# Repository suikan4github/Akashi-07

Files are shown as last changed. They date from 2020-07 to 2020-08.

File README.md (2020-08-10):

# Akashi-07
SDR front end prototype for NUCLEO G431RB and F722ZE

## Functionality
This board is designed for testing the SDR with Quadrature Sampling Detector. 
The connectors can be directly mounted on the Arduino mono Rev3.

The design can be retrieved from the [github](https://github.com/suikan4github/Akashi-07) repository.

The schematics [can be downloaded](docs/Akashi-07.pdf) as PDF format. 

| Function | NUCLEO-G431RB | NUCLEO-F722ZE |
|---|---|---|
| I2C1 SCL | PB8 | PB8 |
| I2C1 SDA | PB9 | PB9 |
| RESCUE | PC9 | PC9 |

The configuration of special ports are :

- PC9 : Open Drain output. To save the struggled I2C device.

## I2C address
The I2C device address of Si5351 PLL is configured as ***0x60*** ( 7bit address ).

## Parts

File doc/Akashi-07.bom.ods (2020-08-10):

Reference | Value | Footprint | Datasheet | DigiKey
C1 | 0.1u | Capacitors_THT:C_Disc_D4.7mm_W2.5mm_P5.00mm | ~
C10 | 0.1u | Capacitors_THT:C_Disc_D4.7mm_W2.5mm_P5.00mm | ~
C11 | 0.01u | Capacitors_THT:C_Disc_D4.7mm_W2.5mm_P5.00mm | ~
C12 | 0.01u | Capacitors_THT:C_Disc_D4.7mm_W2.5mm_P5.00mm | ~
C13 | 10u | Capacitors_THT:CP_Radial_D8.0mm_P2.50mm | ~
C14 | 47u | Capacitors_THT:CP_Radial_D8.0mm_P2.50mm | ~
C15 | 47u | Capacitors_THT:CP_Radial_D8.0mm_P2.50mm | ~
C16 | 47u | Capacitors_THT:CP_Radial_D8.0mm_P2.50mm | ~
C17 | 0.1u | Capacitors_THT:C_Disc_D4.7mm_W2.5mm_P5.00mm | ~
C18 | 0.1u | Capacitors_THT:C_Disc_D4.7mm_W2.5mm_P5.00mm | ~
C19 | 47u | Capacitors_THT:CP_Radial_D8.0mm_P2.50mm | ~
C2 | 0.1u | Capacitors_THT:C_Disc_D4.7mm_W2.5mm_P5.00mm | ~
C3 | 0.1u | Capacitors_THT:C_Disc_D4.7mm_W2.5mm_P5.00mm | ~
C4 | 0.1u | Capacitors_THT:C_Disc_D4.7mm_W2.5mm_P5.00mm | ~
C5 | 0.1u | Capacitors_THT:C_Disc_D4.7mm_W2.5mm_P5.00mm | ~
C6 | 0.1u | Capacitors_THT:C_Disc_D4.7mm_W2.5mm_P5.00mm | ~
C7 | 10u | Capacitors_THT:CP_Radial_D8.0mm_P2.50mm | ~
C8 | 0.1u | Capacitors_THT:C_Disc_D4.7mm_W2.5mm_P5.00mm | ~
C9 | 0.1u | Capacitors_THT:C_Disc_D4.7mm_W2.5mm_P5.00mm | ~
J1 | Conn_Coaxial | Connectors:SMA_THT_Jack_Straight | ~ | WM5543-ND
J2 | Screw_Terminal_01x02 | Connectors_Terminal_Blocks:TerminalBlock_bornier-2_P5.08mm | ~ | 281-2888-ND
J3 | SJ1-3533 | project_lib:Jack_3.5mm_CUI_SJ1-3533NG_Horizontal_CircularHoles | https://www.digikey.jp/product-detail/ja/cui-devices/SJ1-3533/CP1-3533-ND/738695 | CP1-3533N-ND
J4 | Conn_01x08 | Pin_Headers:Pin_Header_Straight_1x08_Pitch2.54mm | ~
J5 | Conn_01x06 | Pin_Headers:Pin_Header_Straight_1x06_Pitch2.54mm | ~
J6 | Conn_01x10 | Pin_Headers:Pin_Header_Straight_1x10_Pitch2.54mm | ~
J7 | Conn_01x08 | Pin_Headers:Pin_Header_Straight_1x08_Pitch2.54mm | ~
JP1 | Jumper_3_Open | Pin_Headers:Pin_Header_Straight_1x03_Pitch2.54mm | ~
JP2 | Jumper_3_Open | Pin_Headers:Pin_Header_Straight_1x03_Pitch2.54mm | ~
L1 | 10mH | Inductors_THT:L_Axial_L7.0mm_D3.3mm_P5.08mm_Vertical_Fastron_MICC | https://www.digikey.jp/product-detail/en/tdk-electronics-inc/B82144A2106J000/495-5615-1-ND/4245955 | AIAP-01-102K-TCT-ND
R1 | 2.2k | Resistors_THT:R_Axial_DIN0204_L3.6mm_D1.6mm_P2.54mm_Vertical | ~
R2 | 2.2k | Resistors_THT:R_Axial_DIN0204_L3.6mm_D1.6mm_P2.54mm_Vertical | ~
R3 | 3.3k | Resistors_THT:R_Axial_DIN0204_L3.6mm_D1.6mm_P2.54mm_Vertical | ~
R4 | 3.3k | Resistors_THT:R_Axial_DIN0204_L3.6mm_D1.6mm_P2.54mm_Vertical | ~
R5 | 100 | Resistors_THT:R_Axial_DIN0204_L3.6mm_D1.6mm_P2.54mm_Vertical | ~
R6 | 100 | Resistors_THT:R_Axial_DIN0204_L3.6mm_D1.6mm_P2.54mm_Vertical | ~
TP1 | TestPoint | Measurement_Points:Measurement_Point_Round-TH_Big | ~
TP2 | TestPoint | Measurement_Points:Measurement_Point_Round-TH_Big | ~
TP3 | TestPoint | Measurement_Points:Measurement_Point_Round-TH_Big | ~
TP4 | TestPoint | Measurement_Points:Measurement_Point_Round-TH_Big | ~
TP5 | TestPoint | Measurement_Points:Measurement_Point_Round-TH_Big | ~
TP6 | TestPoint | Measurement_Points:Measurement_Point_Round-TH_Big | ~
U1 | Si5351A-B-GT | Housings_SSOP:MSOP-10_3x3mm_Pitch0.5mm | https://www.silabs.com/documents/public/data-sheets/Si5351-B.pdf | 336-2399-5-ND
U2 | SN74LVC74APW | Housings_SSOP:TSSOP-14_4.4x5mm_Pitch0.65mm | https://www.tij.co.jp/product/jp/SN74LVC74A | 296-1241-1-ND
U3 | TS5A23157DGSR | project_lib:TS5A23157DGSR | https://www.tij.co.jp/product/jp/TS5A23157 | 296-17076-1-ND
U4 | AD8032ANZ | Housings_DIP:DIP-8_W7.62mm | https://www.analog.com/media/en/technical-documentation/data-sheets/AD8031_8032.pdf | AD8032ANZ-ND
U5 | TLV73333PDBVR | TO_SOT_Packages_SMD:SOT-23-5-handsoldering |  | 296-40673-1-ND
X1 | CSX-750FBC25000000T | Oscillators:Oscillator_SMD_SeikoEpson_SG8002CA-4pin_7.0x5.0mm_HandSoldering | https://www.digikey.jp/product-detail/ja/citizen-finedevice-co-ltd/CSX-750FBC25000000T/300-7246-1-ND/482134 | 300-7246-1-ND

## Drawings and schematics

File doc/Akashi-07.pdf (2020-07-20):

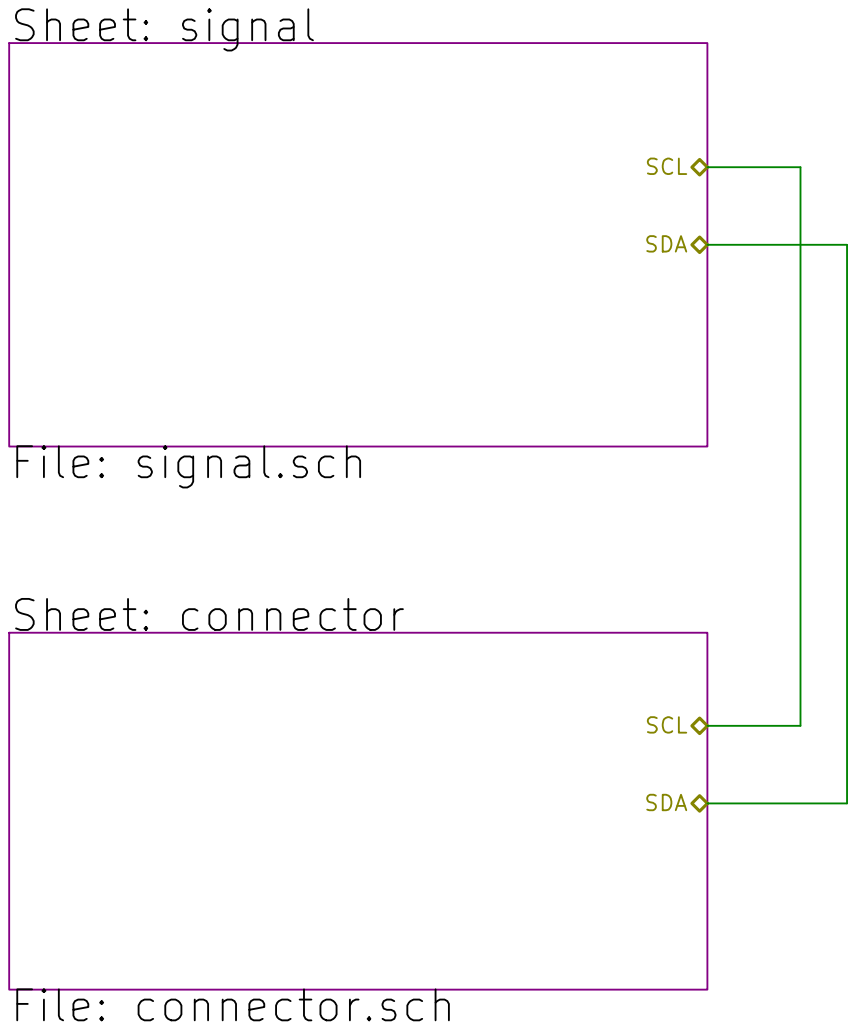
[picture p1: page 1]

SCL SDA Sheet: connector

Top level
File: Akashi-07.sch Sheet: / Direct conversion SDR prototype

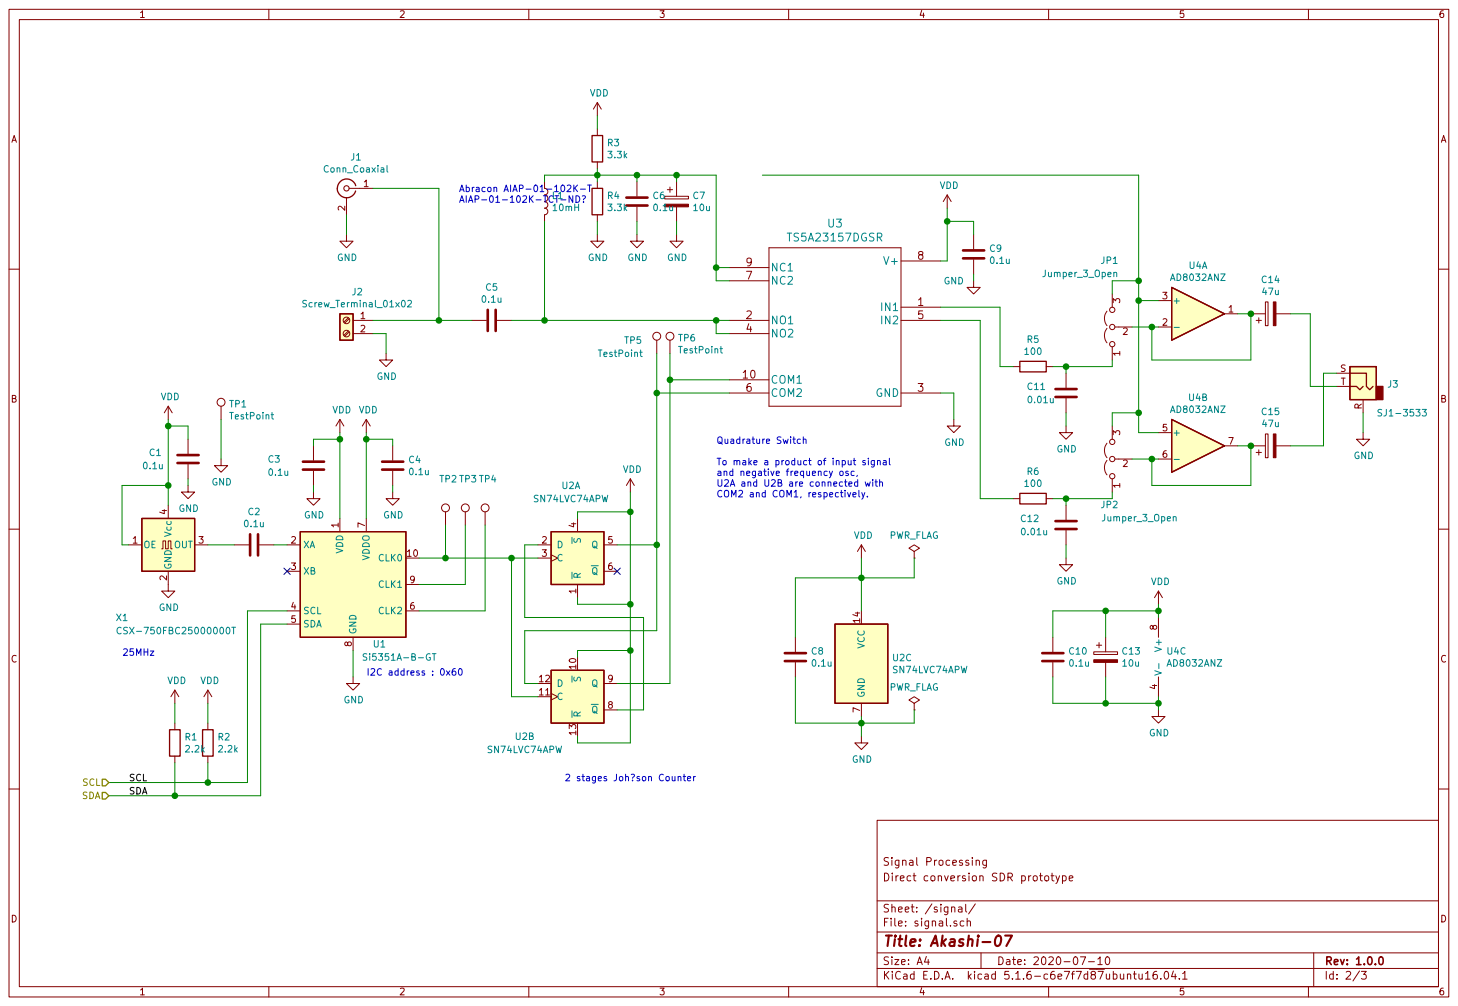
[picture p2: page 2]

and negative frequency osc, U2A and U2B are connected with COM2 and COM1, respectively.

1 CLK0 10 XA 2 XB 3 SCL 4 SDA 5 CLK2 6 VDDO

Direct conversion SDR prototype

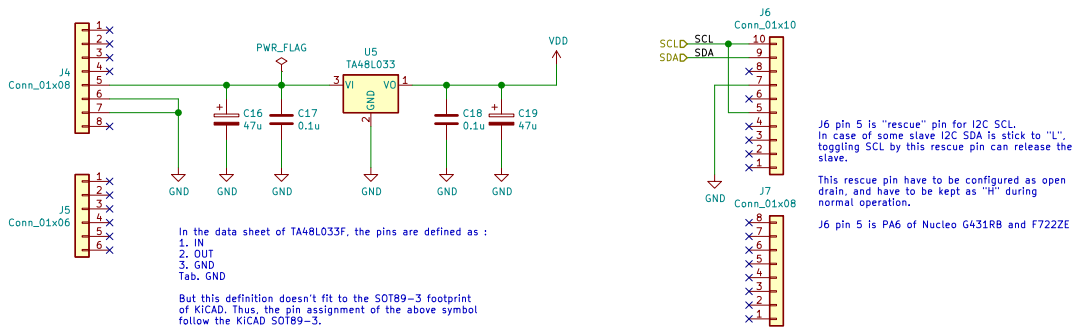
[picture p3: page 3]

In case of some slave I2C SDA is stick to "L",
toggling SCL by this rescue pin can release the slave. This rescue pin have to be configured as open

drain, and have to be kept as "H" during
normal operation.

J6 pin 5 is PA6 of Nucleo G431RB and F722ZE

In the data sheet of TA48L033F, the pins are defined as : 1. IN

But this definition doesn't fit to the SOT89-3 footprint

File: connector.sch Sheet: /connector/ Direct conversion SDR prototype Connectors

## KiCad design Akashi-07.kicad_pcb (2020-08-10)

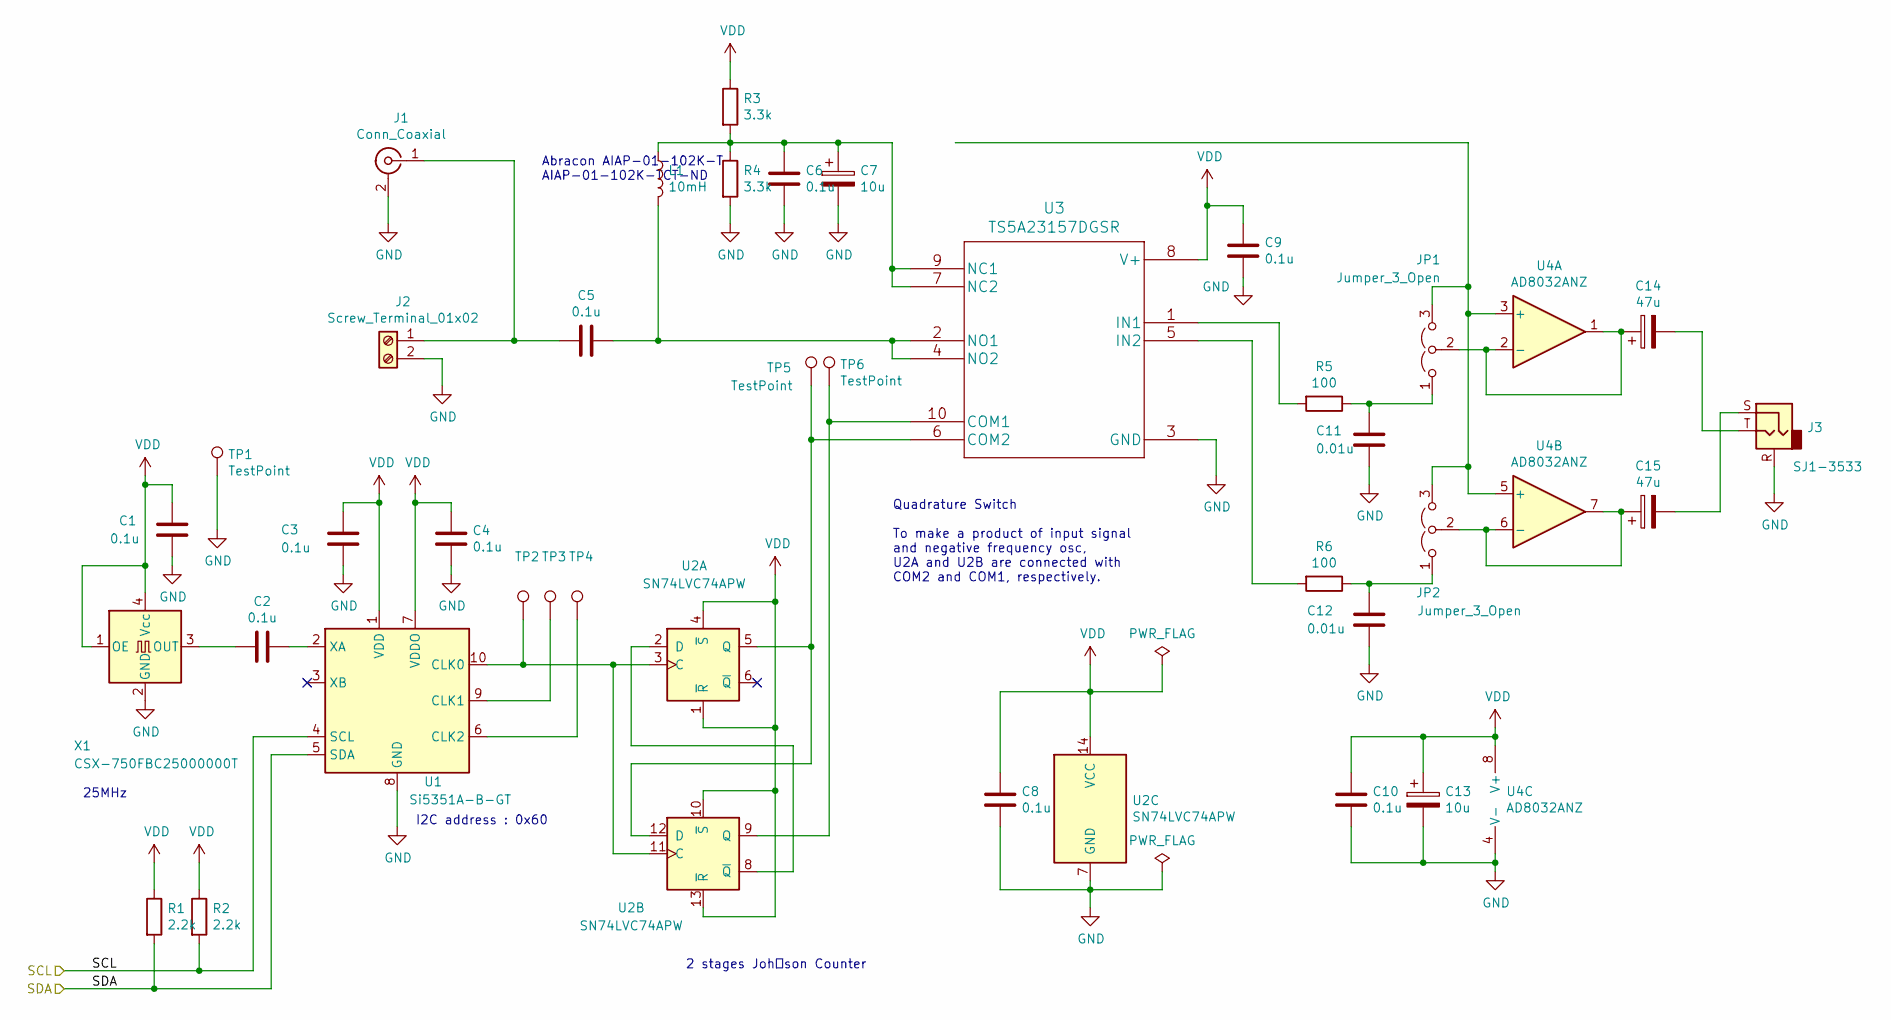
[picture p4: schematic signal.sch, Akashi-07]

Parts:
C1, C2, C3, C4, C5, C6, C8, C9, C10: 0.1u; C_Disc_D4.7mm_W2.5mm_P5.00mm
C7, C13: 10u; CP_Radial_D8.0mm_P2.50mm
C11, C12: 0.01u; C_Disc_D4.7mm_W2.5mm_P5.00mm
C14, C15: 47u; CP_Radial_D8.0mm_P2.50mm
J1: Conn_Coaxial; SMA_THT_Jack_Straight; DigiKey WM5543-ND
J2: Screw_Terminal_01x02; TerminalBlock_bornier-2_P5.08mm; DigiKey 281-2888-ND
J3: SJ1-3533; Jack_3.5mm_CUI_SJ1-3533NG_Horizontal_CircularHoles; DigiKey CP1-3533N-ND
JP1, JP2: Jumper_3_Open; Pin_Header_Straight_1x03_Pitch2.54mm
L1: 10mH; L_Axial_L7.0mm_D3.3mm_P5.08mm_Vertical_Fastron_MICC; DigiKey AIAP-01-102K-TCT-ND
R1, R2: 2.2k; R_Axial_DIN0204_L3.6mm_D1.6mm_P2.54mm_Vertical
R3, R4: 3.3k; R_Axial_DIN0204_L3.6mm_D1.6mm_P2.54mm_Vertical
R5, R6: 100; R_Axial_DIN0204_L3.6mm_D1.6mm_P2.54mm_Vertical
TP1, TP2, TP3, TP4, TP5, TP6: TestPoint; Measurement_Point_Round-TH_Big
U1: Si5351A-B-GT; MSOP-10_3x3mm_Pitch0.5mm; DigiKey 336-2399-5-ND
U2: SN74LVC74APW; TSSOP-14_4.4x5mm_Pitch0.65mm; DigiKey 296-1241-1-ND
U3: TS5A23157DGSR; DigiKey 296-17076-1-ND
U4: AD8032ANZ; DIP-8_W7.62mm; DigiKey AD8032ANZ-ND
X1: CSX-750FBC25000000T; Oscillator_SMD_SeikoEpson_SG8002CA-4pin_7.0x5.0mm_HandSolde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; DigiKey 300-7246-1-ND

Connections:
/connector/SCL: R2.2, U1.4 (SCL); also elsewhere on the board
/connector/SDA: R1.2, U1.5 (SDA); also elsewhere on the board
GND: C1.2, C3.2, C4.2, C6.2, C7.2, C8.2, C9.2, C10.2, C11.2, C12.2, C13.2, J1.2 (Ext), J2.2, J3.R, R4.2, TP1.1, U1.8 (GND), U2.7 (GND), U3.3 (GND), U4.4 (V-), X1.2 (GND); also elsewhere on the board
unnamed: C2.1, U1.2 (XA)
unnamed: C2.2, X1.3 (OUT)
unnamed: C5.1, L1.2, U3.2 (NO1), U3.4 (NO2)
unnamed: C5.2, J1.1 (In), J2.1
unnamed: C6.1, C7.1, L1.1, R3.2, R4.1, U3.7 (NC2), U3.9 (NC1)
unnamed: C11.1, JP1.1 (A), R5.1
unnamed: C12.1, JP2.1 (A), R6.1
unnamed: C14.1, JP1.2 (C), U4.1, U4.2 (-)
unnamed: C14.2, J3.T
unnamed: C15.1, JP2.2 (C), U4.6 (-), U4.7
unnamed: C15.2, J3.S
unnamed: JP1.3 (B), JP2.3 (B), U4.3 (+), U4.5 (+)
unnamed: R5.2, U3.1 (IN1)
unnamed: R6.2, U3.5 (IN2)
unnamed: TP2.1, U1.10 (CLK0), U2.3 (C), U2.11 (C)
unnamed: TP3.1, U1.9 (CLK1)
unnamed: TP4.1, U1.6 (CLK2)
unnamed: TP5.1, U2.5 (Q), U2.12 (D), U3.6 (COM2)
unnamed: TP6.1, U2.9 (Q), U3.10 (COM1)
unnamed: U2.2 (D), U2.8 (~Q)
VDD: C1.1, C3.1, C4.1, C8.1, C9.1, C10.1, C13.1, R1.1, R2.1, R3.1, U1.1 (VDD), U1.7 (VDDO), U2.1 (~R), U2.4 (~S), U2.10 (~S), U2.13 (~R), U2.14 (VCC), U3.8 (V+), U4.8 (V+), X1.1 (OE), X1.4 (Vcc); also elsewhere on the board

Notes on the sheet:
2 stages Johｎson Counter
Quadrature Switch To make a product of input signal and negative frequency osc, U2A and U2B are connected with COM2 and COM1, respectively.
I2C address : 0x60
25MHz
Abracon AIAP-01-102K-T AIAP-01-102K-TCT-ND

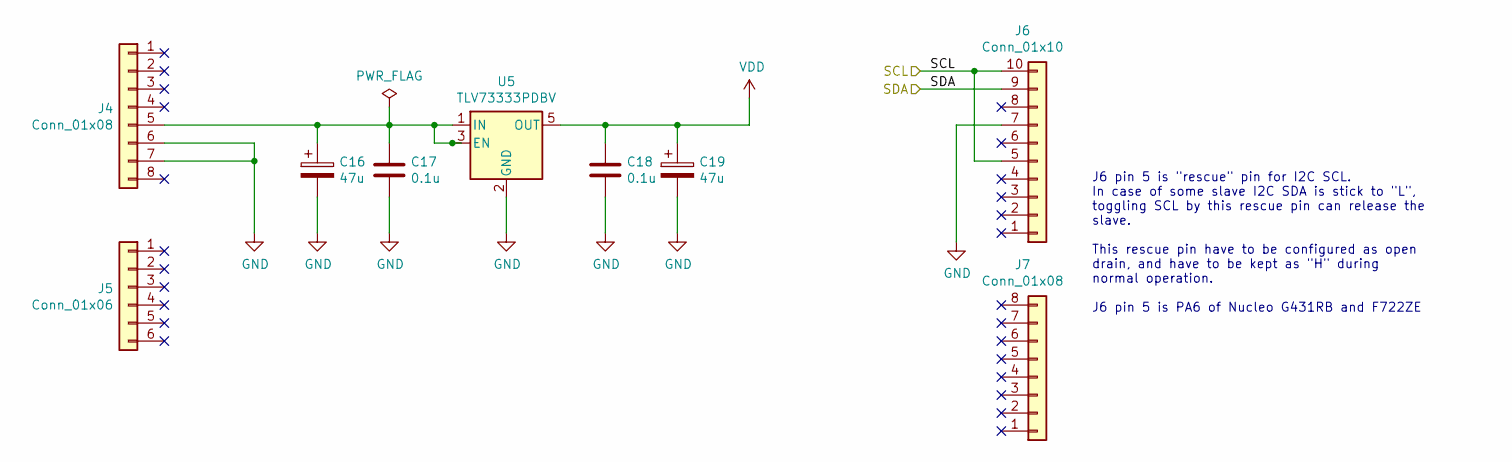
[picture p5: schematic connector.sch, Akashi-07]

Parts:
C16, C19: 47u; CP_Radial_D8.0mm_P2.50mm
C17, C18: 0.1u; C_Disc_D4.7mm_W2.5mm_P5.00mm
J4, J7: Conn_01x08; Pin_Header_Straight_1x08_Pitch2.54mm
J5: Conn_01x06; Pin_Header_Straight_1x06_Pitch2.54mm
J6: Conn_01x10; Pin_Header_Straight_1x10_Pitch2.54mm
U5: TLV73333PDBV; SOT-23-5_HandSoldering

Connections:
/connector/SCL: J6.5, J6.10; also elsewhere on the board
/connector/SDA: J6.9; also elsewhere on the board
GND: C16.2, C17.2, C18.2, C19.2, J4.6, J4.7, J6.7, U5.2 (GND); also elsewhere on the board
unnamed: C16.1, C17.1, J4.5, U5.1 (IN), U5.3 (EN)
VDD: C18.1, C19.1, U5.5 (OUT); also elsewhere on the board

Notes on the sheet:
J6 pin 5 is "rescue" pin for I2C SCL. In case of some slave I2C SDA is stick to "L", toggling SCL by this rescue pin can release the slave. This rescue pin have to be configured as open drain, and have to be kept as "H" during normal operation. J6 pin 5 is PA6 of Nucleo G431RB and F722ZE

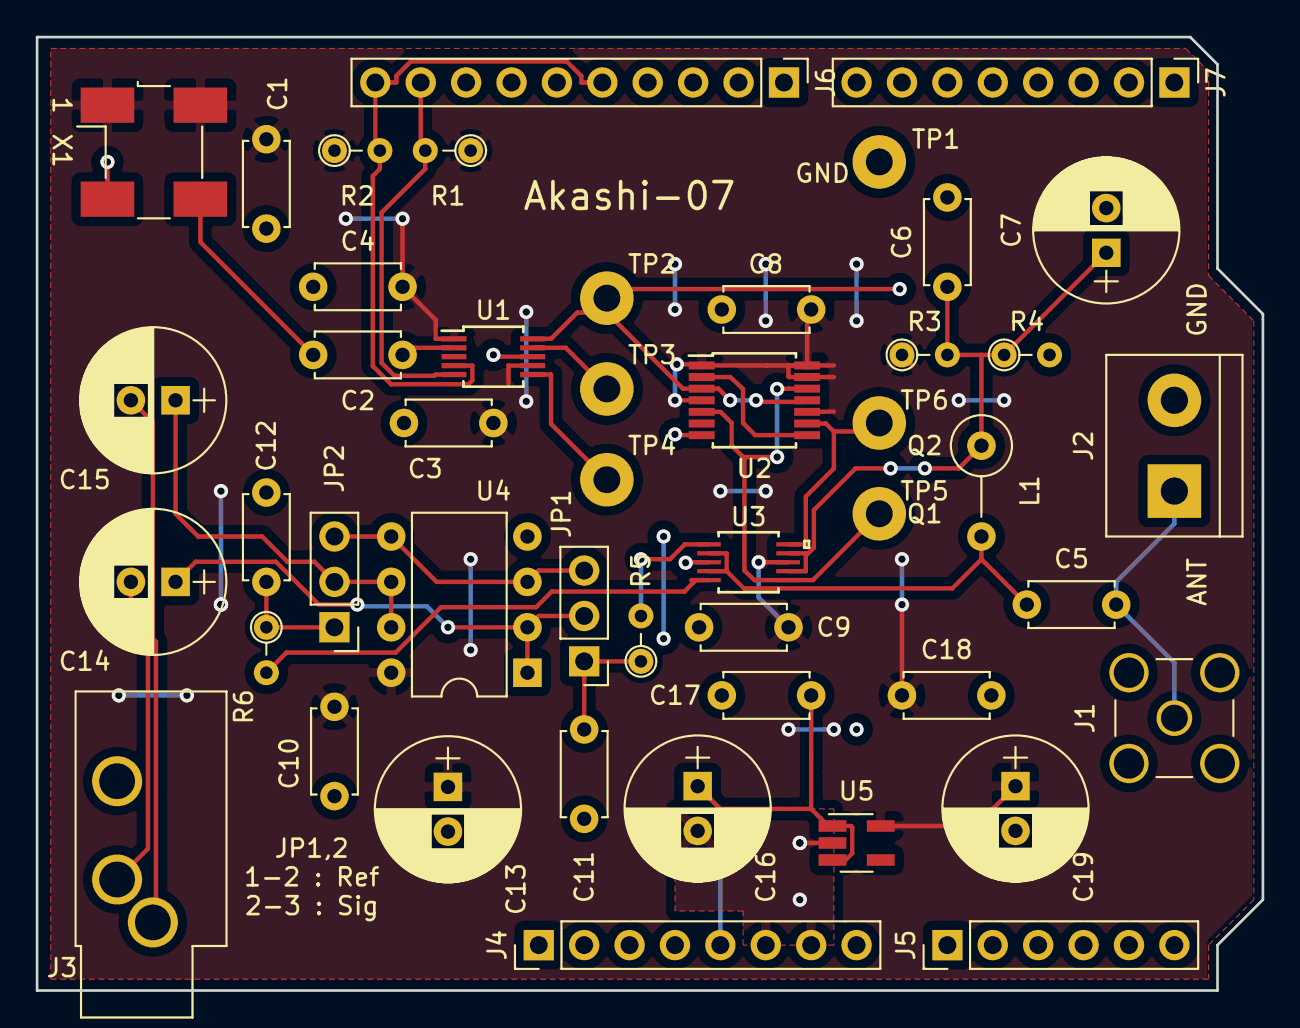
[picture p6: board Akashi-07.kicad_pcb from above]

Board: 2 copper layers, 68.6 x 53.3 mm, 47 parts (0 on the bottom side), 25 nets.

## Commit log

2020-07-10 Added new devices.
    - OpAmps
    - 7474
    [Akashi-07.kicad_pcb, Akashi-07.sch]
2020-07-10 Update the switch symbol
    Singal flow is natural now.
    [Akashi-07.sch]
2020-07-11 Analog part is haf complete
    Need to fix the value.
    Need to re-annotate
    [Akashi-07.sch]
2020-07-11 Editing the schematics.
    Added bypass capacitor values.
    Added foot prints.
    [Akashi-07.sch, connector.sch, signal.sch]
2020-07-11 Schematics are almost done.
    Audio jack is not yet.
    [connector.sch, signal.sch]
2020-07-11 Footprint done.
    Added footprint of the audio jack.
    The documentation link of the each IC is done.
    [Akashi-07.kicad_pcb, Akashi-07.sch, connector.sch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]
2020-07-12 All parts is on the PCB.
    [Akashi-07.kicad_pcb, connector.sch, signal.sch]
2020-07-12 Refined symbol names
    Adjust the position.
    Added copyright and board name.
    [Akashi-07.kicad_pcb]
2020-07-12 Routing finished.
    [Akashi-07.kicad_pcb]
2020-07-12 Added jumper to short the op-amp.
    [Akashi-07.kicad_pcb, signal.sch]
2020-07-13 Change TA48L033F foot print
    Added VDD plane on the FC layer.
    [Akashi-07.kicad_pcb, connector.sch]
2020-07-18 BOM is ready
    [Akashi-07.kicad_pcb, connector.sch, signal.sch]
2020-07-19 update BOM
    [Akashi-07.kicad_pcb, connector.sch, signal.sch]
2020-07-20 Ready for FusionPCB and Digikey
    [Akashi-07.bom.digikey.ods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]

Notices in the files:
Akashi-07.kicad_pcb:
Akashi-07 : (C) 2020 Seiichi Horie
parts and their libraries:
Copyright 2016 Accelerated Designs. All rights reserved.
